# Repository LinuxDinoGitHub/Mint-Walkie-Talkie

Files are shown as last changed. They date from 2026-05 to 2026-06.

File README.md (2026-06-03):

# Mint-Walkie-Talkie
An ATMega328P-powered compact walkie-talkie PCB that fits inside a mint can. Uses the NRF24L01+PA+LNA module to communicate using a custom protocol on a PCB. Range of around 1km.
Mint3
Mint1

## About this project
I've been thinking to make a walkie talkie since the first time I was introduced to PCB design. I have been trying since with the PCB e-ink card project, but that was a side project I never finished (maybe one day). A lot of movies show that walkie-talkies can shrink to absurdly small sizes, which I believe it can with the correct ICs and good PCB layout. But this is my first attempt at making a compact walkie-talkie module with the NRF24L01 module and ATMega328p MCU. The NRF24L01 is known for its long range, around 1km, and it is very compatible and beginner-friendly for hobbyists to use.

### Why did I make this project?
Following my last radio project, I realised I needed some walkie-talkies to match it, so I decided to make this. It is also a test of the world of electronics and how small one can make a walkie-talkie (for now, not so small yet).

### How do you use it?
Simply hold the button on the PCB/mint can, and you'll go into "transmit" mode. Release and it will go into "receive". It is essentially a half-duplex walkie-talkie. 

**Option A: Mint box outer shell**

You should have one of your own mint boxes like the following:


You will need to use a hammer & nail to cut out the holes for the speakers by using a nail to trace the outline, then cutting it out. **Tip: use the [stencil provided here](https://github.com/LinuxDinoGitHub/Mint-Walkie-Talkie/blob/main/assets/Stencil_print_in_a4.pdf) to print out and mark the traces.** More photos coming soon.

**Dimensions:**




A: 8.5mm

B: 10mm

C: 20mm

D: 3.5mm

The PTT button will need to be 3D printed ([file here](https://github.com/LinuxDinoGitHub/Mint-Walkie-Talkie/blob/main/models/button.step)) and assembled by press-fitting from the bottom (use glue to help if you punched your hole too big) to the 6mm button on the PCB trace through the mint box, using the taper to lock it in place.



**Option B: 3D printed replica mint box casing ([Link here](https://github.com/LinuxDinoGitHub/Mint-Walkie-Talkie/blob/main/models/3D_printed_case.step))**

If you don't have a mint box, you can use a 3D printed case and save yourself the hassle of manually making the holes. Print the file linked above; the button is included, assembly same as above.

## Key features
- PPT Button, half-duplex system as mentioned above
- LED signifier
- Can fit into a mint can
- Powered by a 3.7 V LiPo battery with a rechargeable battery protection module (TP4056)
- 8Ohm 1W Speaker amplified with PAM8403
- Microphone input with MAX9814

## [Schematic](https://github.com/LinuxDinoGitHub/Mint-Walkie-Talkie/tree/main/pcb)


## [PCB](https://github.com/LinuxDinoGitHub/Mint-Walkie-Talkie/tree/main/pcb)

Simple 3-layer PCB, with a ground plane for removing noise.



### First layer



### Second layer (Ground plane)



### Third layer



## 3D View

### Front


### Back


## Example use case in Mint can
Mint3

## [Firmware](https://github.com/LinuxDinoGitHub/Mint-Walkie-Talkie/blob/main/firmware/mint.ino)
The firmware requires another Arduino (Uno, Mega, Nano, etc.) to program the ATMega328P. This is done with the 6 pins on the PCB (see below); for more details, check out this [Arduino article on how to program an ATMega328P](https://docs.arduino.cc/built-in-examples/arduino-isp/ArduinoToBreadboard/). All the pins you need are provided in the header pins.



## BOM
[BOM](https://github.com/LinuxDinoGitHub/Mint-Walkie-Talkie/blob/main/BOM_with_links.csv)** with links **to vendors and sources of material.
[BOM](https://github.com/LinuxDinoGitHub/Mint-Walkie-Talkie/blob/main/BOM_KiCAD_generated.csv) generated by KiCAD with components listing.
The project will cost an average of $6 per walkie-talkie, but most of the materials require bulk purchases.

## Zine page
[1779976642758-aed0d11d-6999-48d8-a8b2-eb19d6b463cd_1](https://github.com/LinuxDinoGitHub/Mint-Walkie-Talkie/blob/main/Mint_zine_final.pdf)

## Credits
Thank you to the great documentation from [RF24 library](https://github.com/nRF24/RF24), a really convenient and high-speed data transfer library for the NRF24L01.

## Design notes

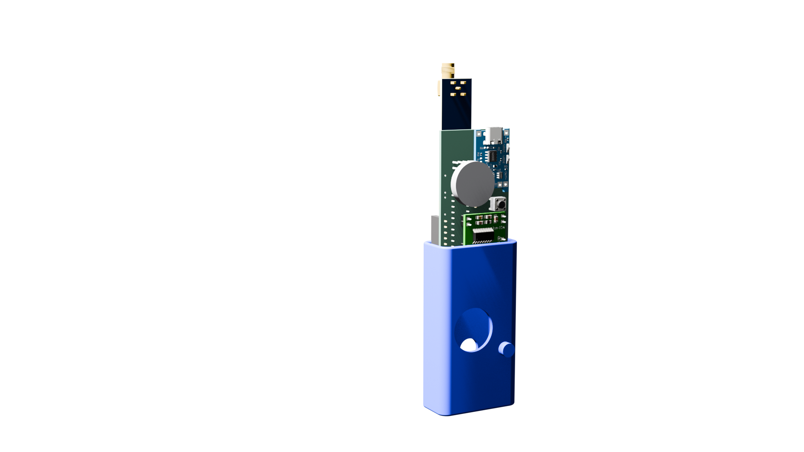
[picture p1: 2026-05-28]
assets/Mint3.png

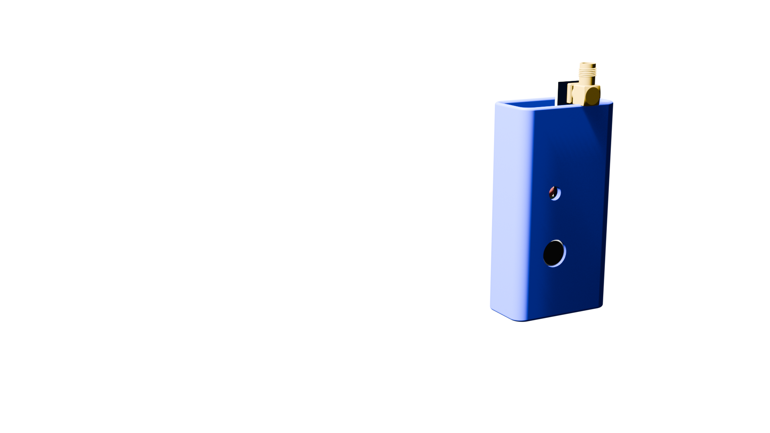
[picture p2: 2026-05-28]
assets/Mint1.png

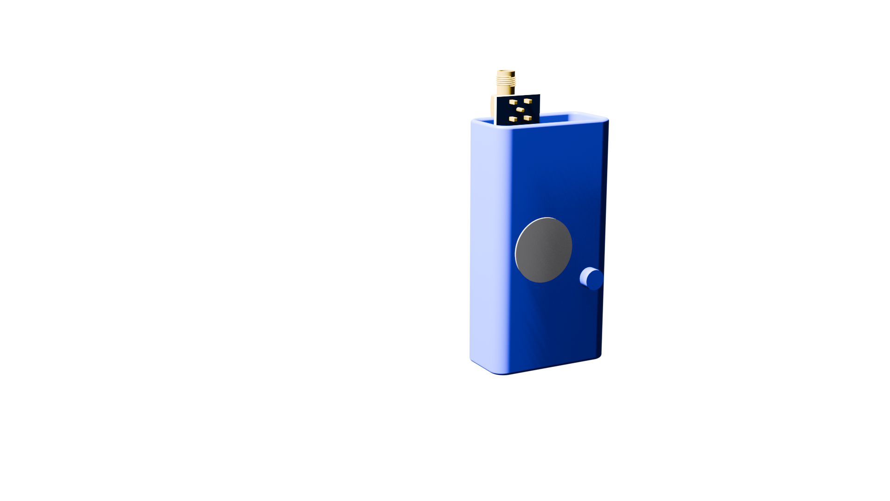
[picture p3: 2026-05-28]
assets/Mint2.png

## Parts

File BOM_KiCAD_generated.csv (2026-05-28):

Reference | Qty | Value | DNP | Exclude from BOM | Exclude from Board | Footprint | Datasheet
C1,C2 | 2 | 22p |  |  |  | Capacitor_THT:C_Axial_L3.8mm_D2.6mm_P7.50mm_Horizontal
D1 | 1 | LED |  |  |  | Connector_PinHeader_2.54mm:PinHeader_1x02_P2.54mm_Vertical
J1 | 1 | Conn_01x06_Pin |  |  |  | Connector_PinSocket_2.54mm:PinSocket_1x06_P2.54mm_Vertical
LS1 | 1 | Speaker |  |  |  | Connector_PinHeader_2.54mm:PinHeader_1x02_P2.54mm_Vertical
MAX9814 | 1 |  |  |  |  | Connector_PinSocket_2.54mm:PinSocket_1x05_P2.54mm_Vertical
R1 | 1 | 10k |  |  |  | Resistor_THT:R_Axial_DIN0204_L3.6mm_D1.6mm_P2.54mm_Vertical
SW1 | 1 | SW_Push |  |  |  | Button_Switch_THT:SW_PUSH_6mm_H5mm
U1 | 1 | NRF24L01_Breakout |  |  |  | RF_Module:nRF24L01_Breakout | http://www.nordicsemi.com/eng/content/download/2730/34105/file/nRF24L01_Product_Specification_v2_0.pdf
U2 | 1 | ATmega328-P |  |  |  | Package_DIP:DIP-28_W7.62mm | http://ww1.microchip.com/downloads/en/DeviceDoc/ATmega328_P%20AVR%20MCU%20with%20picoPower%20Technology%20Data%20Sheet%2040001984A.pdf
U3 | 1 | pam8403 |  |  |  | pam8403:pam8403
U4 | 1 | MCP1700x-330xxMB |  |  |  | Package_TO_SOT_SMD:SOT-89-3 | http://ww1.microchip.com/downloads/en/DeviceDoc/20001826D.pdf
U5 | 1 |  |  |  |  | TP4056-18650-master:TP4056-18650
Y1 | 1 | 8Mhz Crystal |  |  |  | Connector_PinHeader_2.54mm:PinHeader_1x02_P2.54mm_Vertical

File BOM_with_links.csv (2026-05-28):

Reference | Qty | Value | DNP | Exclude from BOM | Exclude from Board | Footprint | Datasheet | Source | Price / pc (HKD) | Total price (HKD)
C1,C2 | 2 | 22p |  |  |  | Capacitor_THT:C_Axial_L3.8mm_D2.6mm_P7.50mm_Horizontal |  | https://www.aliexpress.com/item/1005011747293156.html?curPageLogUid=MnmnogHslDg0 | 0.09 | 0.19
D1 | 1 | LED |  |  |  | Connector_PinHeader_2.54mm:PinHeader_1x02_P2.54mm_Vertical |  | https://www.aliexpress.com/item/4000857328687.html?curPageLogUid=oDQofqunElDL | 0.05 | 0.05
J1 | 1 | Conn_01x06_Pin |  |  |  | Connector_PinSocket_2.54mm:PinSocket_1x06_P2.54mm_Vertical |  | https://www.aliexpress.com/item/1005010520348816.html?curPageLogUid=D1pREEWKOW1V | 0.32 | 0.32
LS1 | 1 | Speaker |  |  |  | Connector_PinHeader_2.54mm:PinHeader_1x02_P2.54mm_Vertical |  | https://www.aliexpress.com/item/1005006150706417.html?curPageLogUid=Eenk0Q22XDIz | 2.48 | 2.48
MAX9814 | 1 |  |  |  |  | Connector_PinSocket_2.54mm:PinSocket_1x05_P2.54mm_Vertical |  | https://www.aliexpress.com/item/1005006468621971.html?curPageLogUid=WngdRYyXcwDX | 4.93 | 4.93
R1 | 1 | 10k |  |  |  | Resistor_THT:R_Axial_DIN0204_L3.6mm_D1.6mm_P2.54mm_Vertical |  | https://www.aliexpress.com/item/1005007643210127.html?curPageLogUid=wxU1nC2FHuNC | 0.93 | 0.93
SW1 | 1 | SW_Push |  |  |  | Button_Switch_THT:SW_PUSH_6mm_H5mm |  | https://www.aliexpress.com/item/10000000781310.html?curPageLogUid=HLg83V4vo32Z | 0.14 | 0.14
U1 | 1 | NRF24L01_Breakout |  |  |  | RF_Module:nRF24L01_Breakout | http://www.nordicsemi.com/eng/content/download/2730/34105/file/nRF24L01_Product_Specification_v2_0.pdf | https://www.aliexpress.com/item/1005008646429527.html?curPageLogUid=TWs729VWR8cE | 10.14 | 10.14
U2 | 1 | ATmega328-P |  |  |  | Package_DIP:DIP-28_W7.62mm | http://ww1.microchip.com/downloads/en/DeviceDoc/ATmega328_P%20AVR%20MCU%20with%20picoPower%20Technology%20Data%20Sheet%2040001984A.pdf | https://www.aliexpress.com/item/1005004712591054.html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 | 15.42 | 15.42
U3 | 1 | pam8403 |  |  |  | pam8403:pam8403 |  | https://www.aliexpress.com/item/1005010446104300.html?curPageLogUid=wQtVzB21i0SP | 1.01 | 1.01
U4 | 1 | MCP1700x-330xxMB |  |  |  | Package_TO_SOT_SMD:SOT-89-3 | http://ww1.microchip.com/downloads/en/DeviceDoc/20001826D.pdf | https://www.aliexpress.com/item/32808973510.html?curPageLogUid=DOizGYwHi9EO | 0.63 | 0.63
U5 | 1 |  |  |  |  | TP4056-18650-master:TP4056-18650 |  | https://www.aliexpress.com/item/1005008145821171.html?curPageLogUid=byWhCyQtm6Nj | 3.83 | 3.83
Y1 | 1 | 8Mhz Crystal |  |  |  | Connector_PinHeader_2.54mm:PinHeader_1x02_P2.54mm_Vertical |  | https://www.aliexpress.com/item/33049097806.html?curPageLogUid=p3HGys7jqKhs | 0.25 | 0.25
PCB | 1 |  |  |  |  |  |  |  | 10.97 | 10.97
 |  |  |  |  |  |  |  |  | Total (HKD) | 51.28
 |  |  |  |  |  |  |  |  | Total (USD) | 6.54

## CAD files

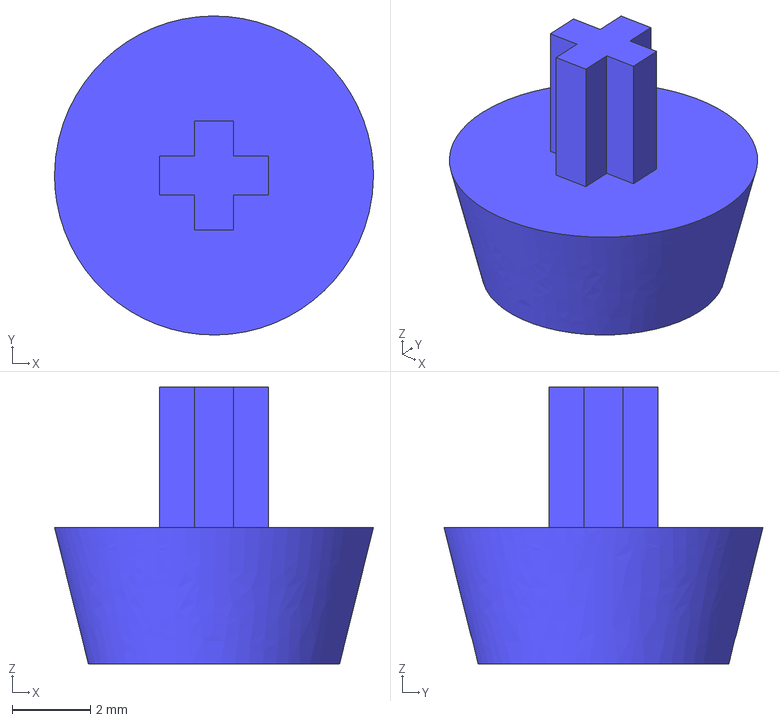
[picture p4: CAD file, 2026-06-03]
models/button.step
8.18 x 8.18 x 7.10 mm

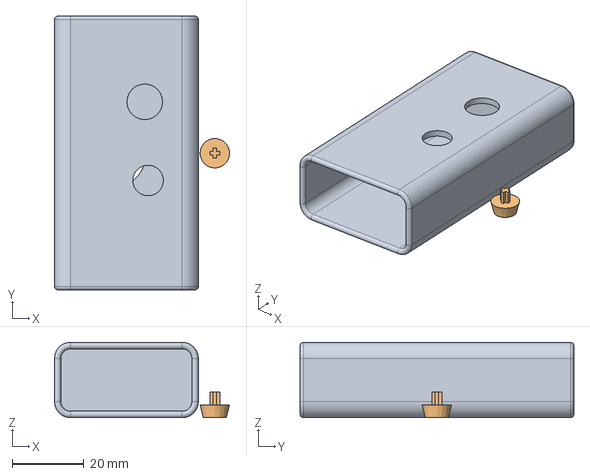
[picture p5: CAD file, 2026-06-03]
models/3D_printed_case.step
48.8 x 76.3 x 21.0 mm

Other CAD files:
models/3D_printed_case.f3d
models/Mint.blend

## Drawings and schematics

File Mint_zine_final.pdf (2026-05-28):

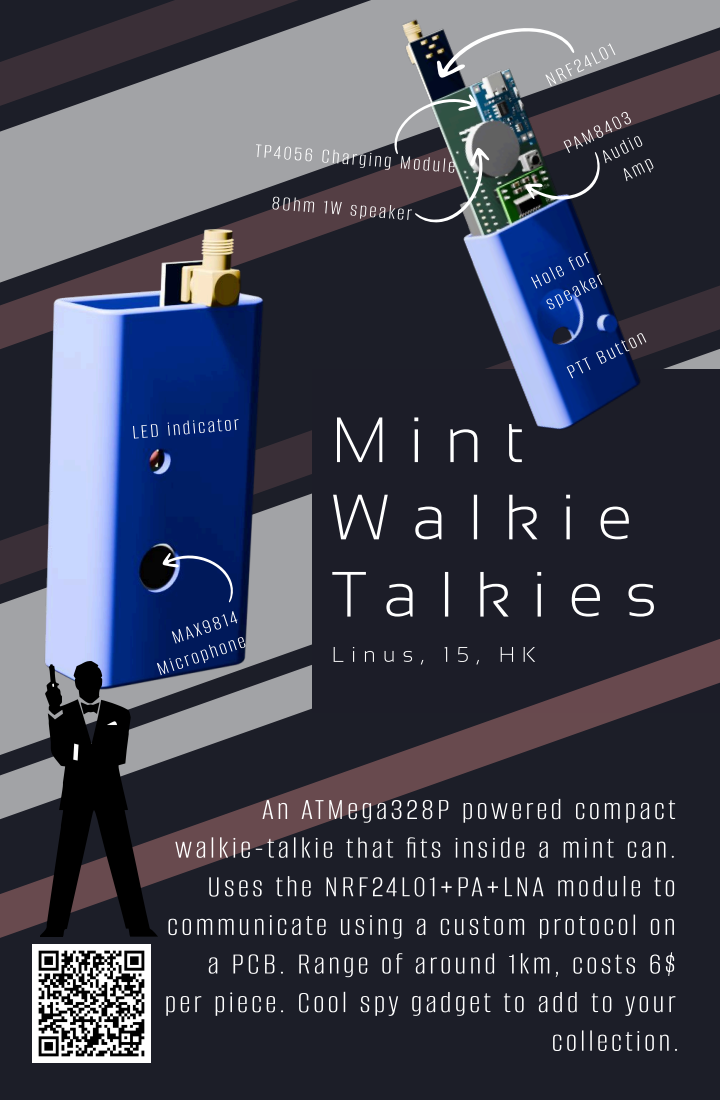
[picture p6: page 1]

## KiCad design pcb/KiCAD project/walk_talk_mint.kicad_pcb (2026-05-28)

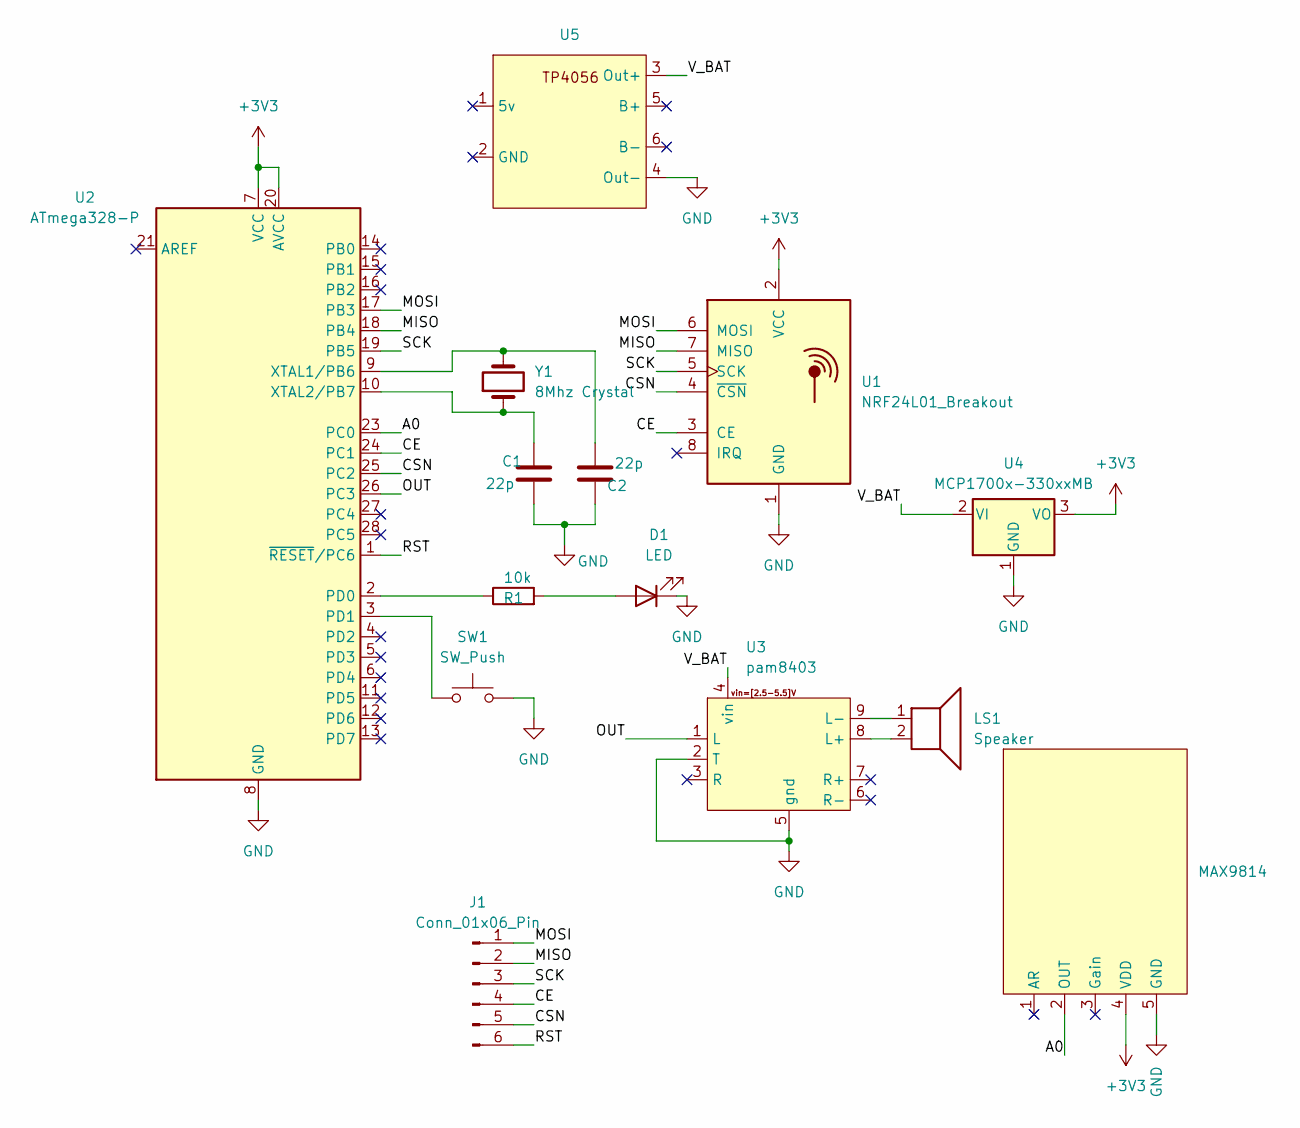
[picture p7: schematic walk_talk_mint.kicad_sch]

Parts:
C1, C2: 22p; C_Axial_L3.8mm_D2.6mm_P7.50mm_Horizontal
D1: LED; PinHeader_1x02_P2.54mm_Vertical
J1: Conn_01x06_Pin; PinSocket_1x06_P2.54mm_Vertical
LS1: Speaker; PinHeader_1x02_P2.54mm_Vertical
MAX9814: PinSocket_1x05_P2.54mm_Vertical
R1: 10k; R_Axial_DIN0204_L3.6mm_D1.6mm_P2.54mm_Vertical
SW1: SW_Push; SW_PUSH_6mm_H5mm
U1: NRF24L01_Breakout; nRF24L01_Breakout
U2: ATmega328-P; DIP-28_W7.62mm
U3: pam8403
U4: MCP1700x-330xxMB; SOT-89-3
U5: TP4056-18650
Y1: 8Mhz Crystal; PinHeader_1x02_P2.54mm_Vertical

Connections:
+3V3: MAX9814.4 (VDD), U1.2 (VCC), U2.7 (VCC), U2.20 (AVCC), U4.3 (VO)
/A0: MAX9814.2 (OUT), U2.23 (PC0)
/CE: J1.4, U1.3 (CE), U2.24 (PC1)
/CSN: J1.5, U1.4 (~CSN), U2.25 (PC2)
/MISO: J1.2, U1.7 (MISO), U2.18 (PB4)
/MOSI: J1.1, U1.6 (MOSI), U2.17 (PB3)
/OUT: U2.26 (PC3), U3.1 (L)
/RST: J1.6, U2.1 (~RESET/PC6)
/SCK: J1.3, U1.5 (SCK), U2.19 (PB5)
/V_BAT: U3.4 (vin), U4.2 (VI), U5.3 (Out+)
GND: C1.2, C2.1, D1.1 (K), MAX9814.5 (GND), SW1.2, U1.1 (GND), U2.8 (GND), U2.22 (GND), U3.2 (T), U3.5 (gnd), U4.1 (GND), U5.4 (Out-)
unnamed: D1.2 (A), R1.2
unnamed: R1.1, U2.2 (PD0)
unnamed: SW1.1, U2.3 (PD1)
unnamed: C2.2, U2.9 (XTAL1/PB6), Y1.2
unnamed: C1.1, U2.10 (XTAL2/PB7), Y1.1
unnamed: LS1.2, U3.8 (L+)
unnamed: LS1.1, U3.9 (L-)

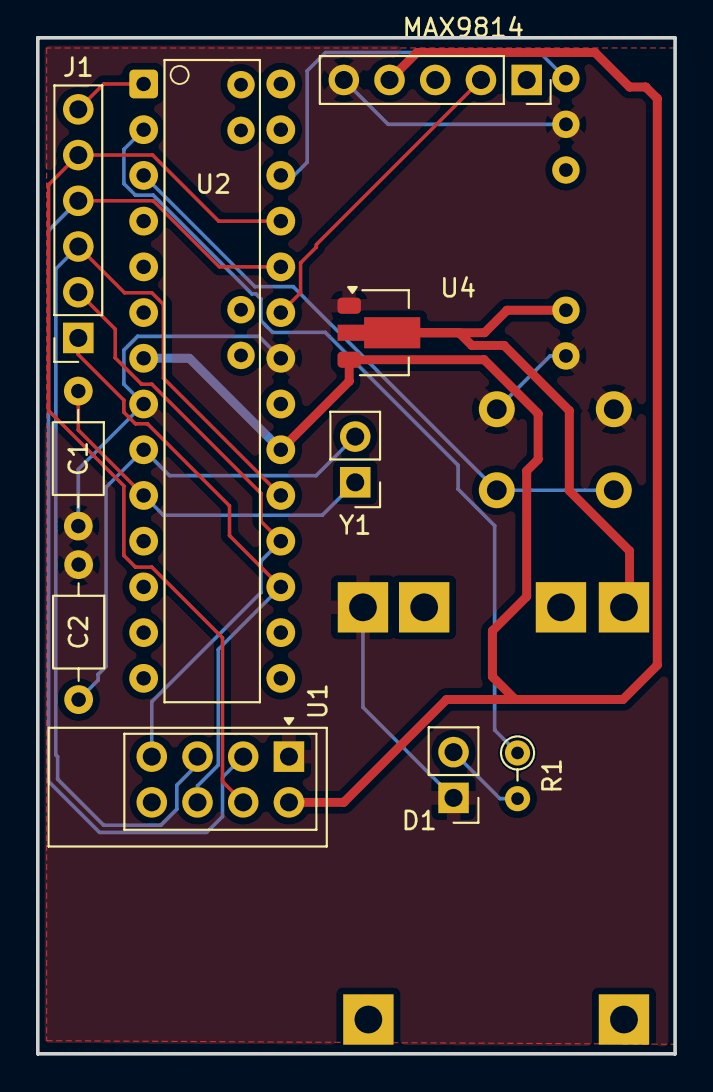
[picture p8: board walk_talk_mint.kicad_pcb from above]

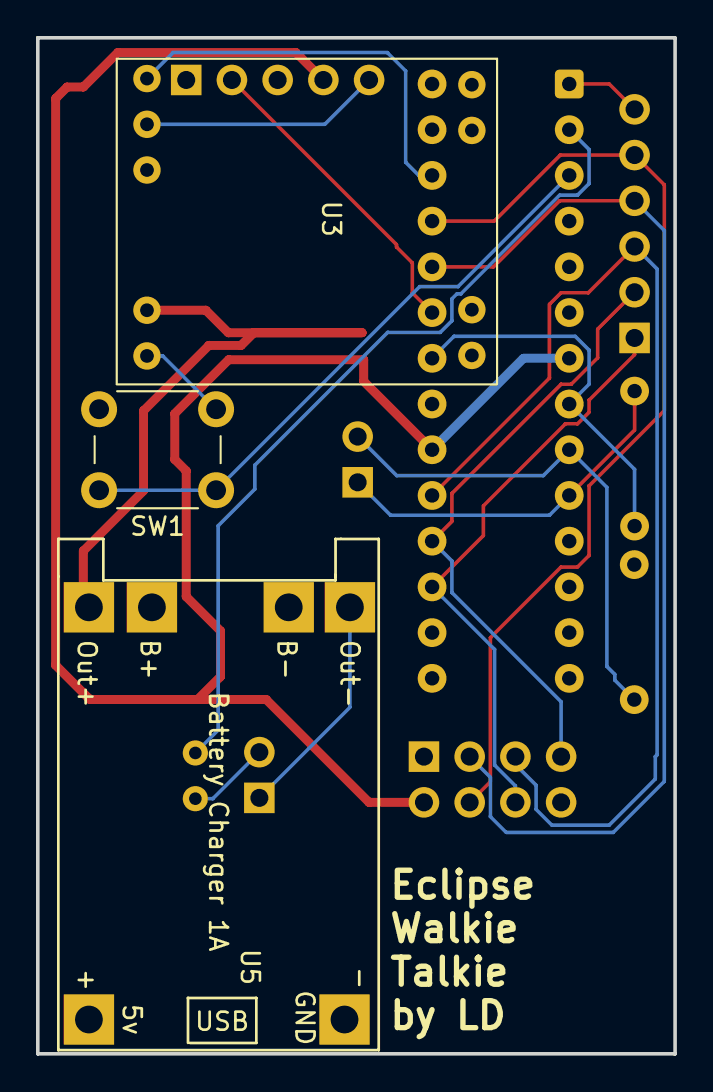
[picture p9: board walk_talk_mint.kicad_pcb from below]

Board: 2 copper layers, 35.4 x 56.4 mm, 13 parts (3 on the bottom side), 16 nets.

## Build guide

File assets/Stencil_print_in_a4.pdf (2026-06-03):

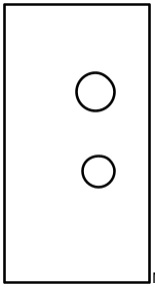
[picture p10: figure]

Microphone side with button

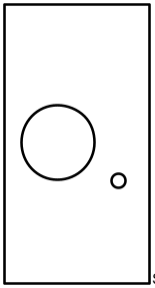
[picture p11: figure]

Speaker side

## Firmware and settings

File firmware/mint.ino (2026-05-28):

#include <SPI.h>
#include <RF24.h>
// Definitions, not sure if these are correct due to lack of testing material
#define PTT_PIN 2
#define AUDIO_IN A0
#define AUDIO_OUT 11
#define LED 16

RF24 radio(9, 10);
const byte address[6] = "00001";
uint8_t audioBuffer[32];
volatile uint8_t bufferIndex = 0;

void setup() {
  pinMode(PTT_PIN, INPUT_PULLUP);
  pinMode(AUDIO_OUT, OUTPUT);
  
  radio.begin();
  radio.openWritingPipe(address);
  radio.openReadingPipe(1, address);
  radio.setPALevel(RF24_PA_MAX);
  radio.setDataRate(RF24_2MBPS); // High speed for audio data

}

void loop() {
  // Check if button is pressed
  if (digitalRead(PTT_PIN) == LOW) {
    // TRANSMIT MODE
    radio.stopListening();
    digitalWrite(LED, HIGH);
    if (bufferIndex >= 32) {
      radio.write(&audioBuffer, 32);
      bufferIndex = 0;
    }
  } else {
    // RECEIVE MODE
    radio.startListening();
    digitalWrite(LED, LOW);
    if (radio.available()) {
      digitalWrite(LED, HIGH);
      radio.read(&audioBuffer, 32);
      for(int i=0; i<32; i++) {
        analogWrite(AUDIO_OUT, audioBuffer[i]); // Simplistic representation
        delayMicroseconds(125); // 1/8000Hz = 125us, not sure if this is correct, from gemini
      }
    }
  }
}

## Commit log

2026-05-28 Added pcb, assets, firmware, and BOM files
    [BOM_KiCAD_generated.csv, BOM_with_links.csv, Mint.blend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]
2026-05-28 Enhance README with project details and usage
    Expanded project description and added usage instructions, features, and links to firmware and schematic.
2026-05-28 Added BOM
2026-05-28 Update README with assembly instructions and image
    Added assembly notes and image reference for mint box.
2026-06-03 Updated pcb files formatting
    [walk_talk_mint-B_Cu.gbr, walk_talk_mint-B_Mask.gbr, walk_talk_mint-B_Paste.gbr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]
2026-06-03 Revise README with assembly tips and resource links
    Updated instructions for assembly and added links to BOM and RF24 library documentation.
2026-06-03 added step files for assembly
    [3D_printed_case.step, button.step]
2026-06-03 Enhance README with detailed assembly instructions
    Updated instructions and links for assembly and firmware.
2026-06-03 added fusion fiel
    [3D_printed_case.f3d]
